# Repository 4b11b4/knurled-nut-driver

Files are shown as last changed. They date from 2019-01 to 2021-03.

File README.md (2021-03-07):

# Knurled Nut Driver
## Description
3D printed drill bit designed for tightening knurled nuts on 3.5mm jacks.<br>
Knurled nuts are common in [Eurorack](http://www.doepfer.de/a100_man/a100m_e.htm) systems.

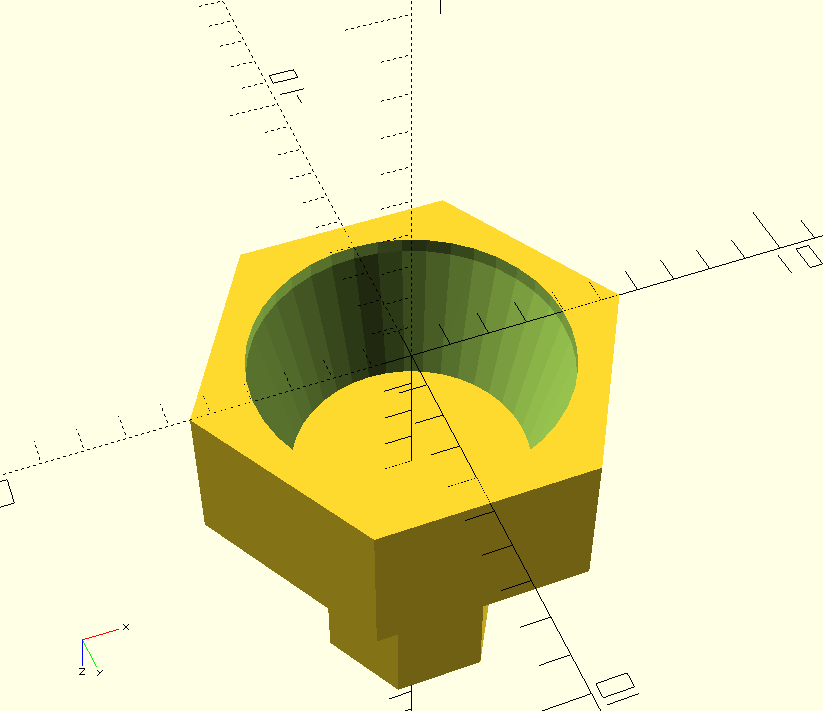
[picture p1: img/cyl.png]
Knurled Nut Suction Cup


## Instructions for Printing and Use
See a [writeup](https://4b11b4.com/k2nd.html) here.

## Features
* __alignment__: no need to align the two metal extensions
* __plastic__: if you have an accident, you will not scratch the module
* __inexpensive__: very little material, easily replaceable
* __parametric__: can be modified to multiple drill bit sizes
* __durable__: no small tips which can break off or become damaged
* __simple__: very easy to print, simple design which uses friction forces
* __useable with power tools__: most people will warn you
  (generally) to never use
  power tools for tightening these nuts, as over tightening may damage the
  jack.

## Why?
This design will not damage your jack
if used with a power tool.
When the nut is tightened, the design of the
bit will simply cause it to slip rather than over-torque the nut.
(note: of course, you can <b>still</b> overtorque by pressing down too hard
<br><br>
In this scenario, you may cause extra wear
to the bit, but the jack will not be damaged.<br><br>

Even more preferable is to use a small precision electric drill with an
adjustable clutch to set the desired torque. You can see (and hear) this
in action [here](https://www.youtube.com/watch?v=a87VO5FZRd8).

## Recommended Power Tool
[See the writeup](https://4b11b4.com/k2nd.html) for links to the two power tools I used.
Those affiliate links don't work...

## Alternative Tools:
[Exploding Shed](https://www.exploding-shed.com/shop-catalogue/various/)

[Xicon Driver](https://www2.mouser.com/ProductDetail/Xicon/382-0006/?qs=sGAEpiMZZMv9NFGNGF1lwkQZlGfFTqj%252b)

[Adachi-san Driver](http://www.tabiwallah.com/radiowallah/shops/jacknut.html)

[Philmore](https://www.fullcompass.com/prod/026125-philmore-nt500-knurled-nut-tool-)

[Homemade](https://www.muffwiggler.com/forum/viewtopic.php?t=114781&start=all&postdays=0&postorder=asc)

[Also homemade](https://www.muffwiggler.com/forum/viewtopic.php?t=5408)

[Homemade 3](http://www.n1gy.com/homebrewed-audio-jack-tool.html)

[Wiha](https://www.wihatools.com/precision-nut-driver-3-5-x-60mm)

[Wiha Bit](https://www.wihatools.com/sys-4-nut-driver-blade-3-5mm)

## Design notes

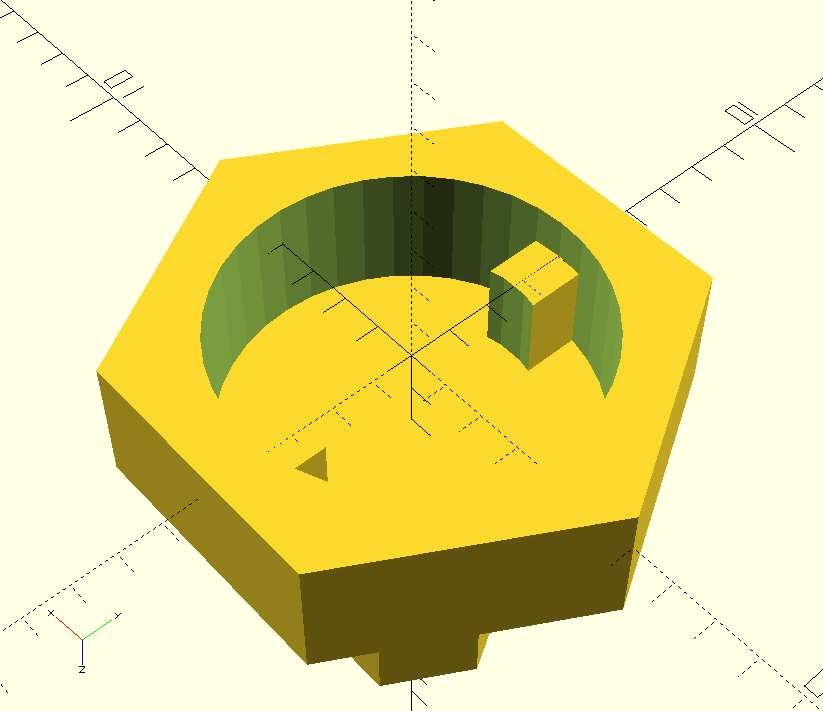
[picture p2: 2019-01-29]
img/nub.png

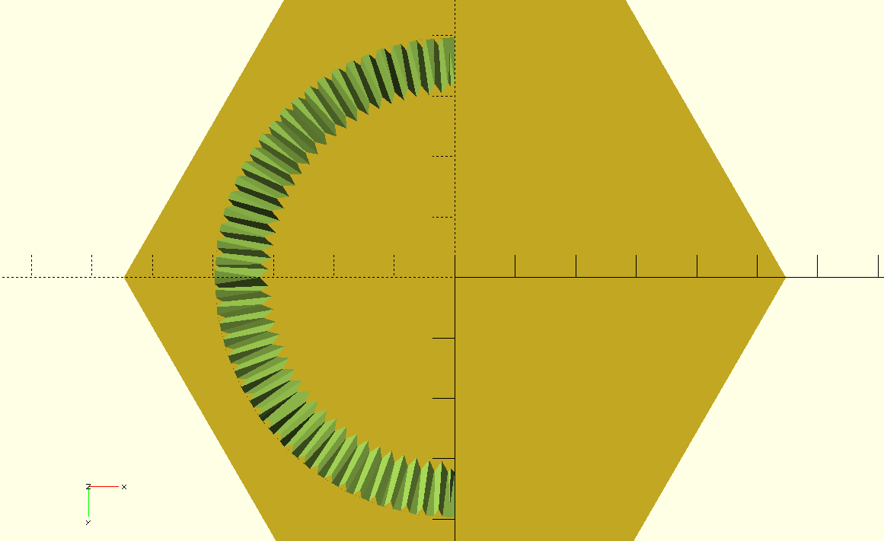
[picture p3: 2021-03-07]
img/cyl_cutout_30deg_teeth_bottom.png

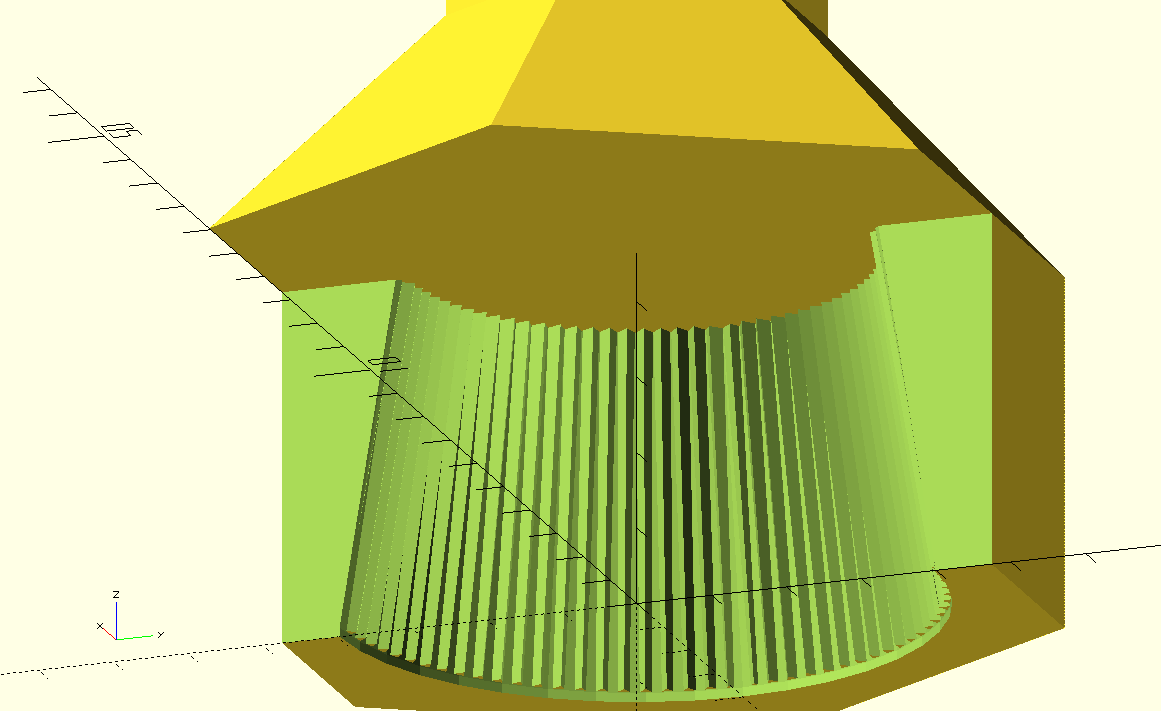
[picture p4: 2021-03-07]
img/cyl_cutout_30deg_teeth.png

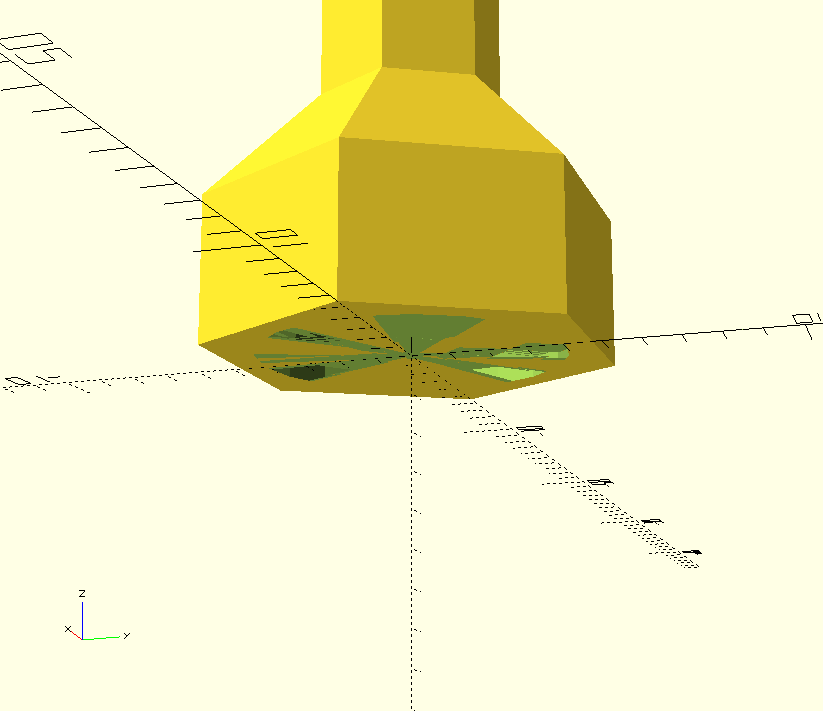
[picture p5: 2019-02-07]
img/cyl_cutout_20deg.png

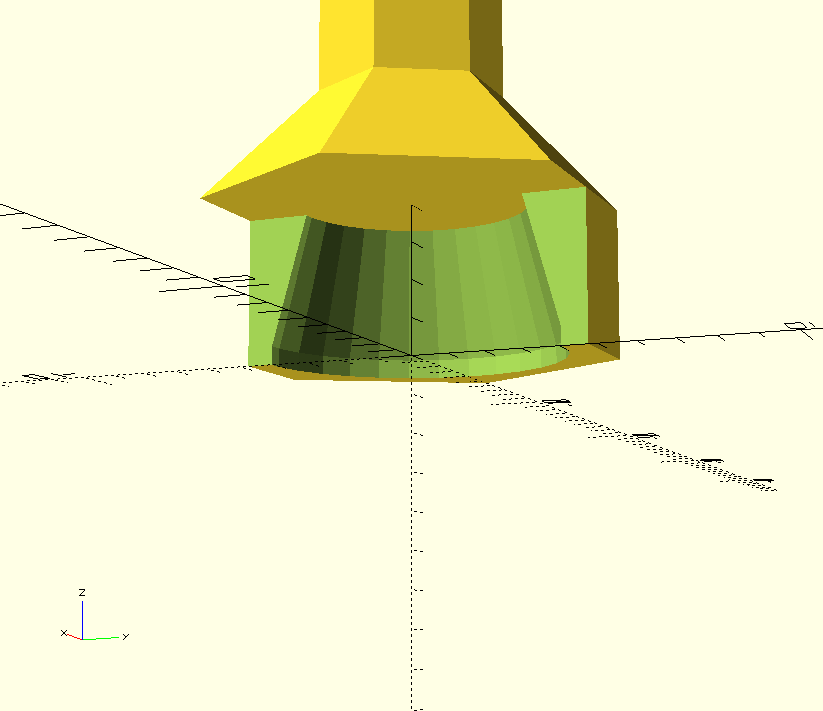
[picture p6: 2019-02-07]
img/cyl_cutout_30deg.png

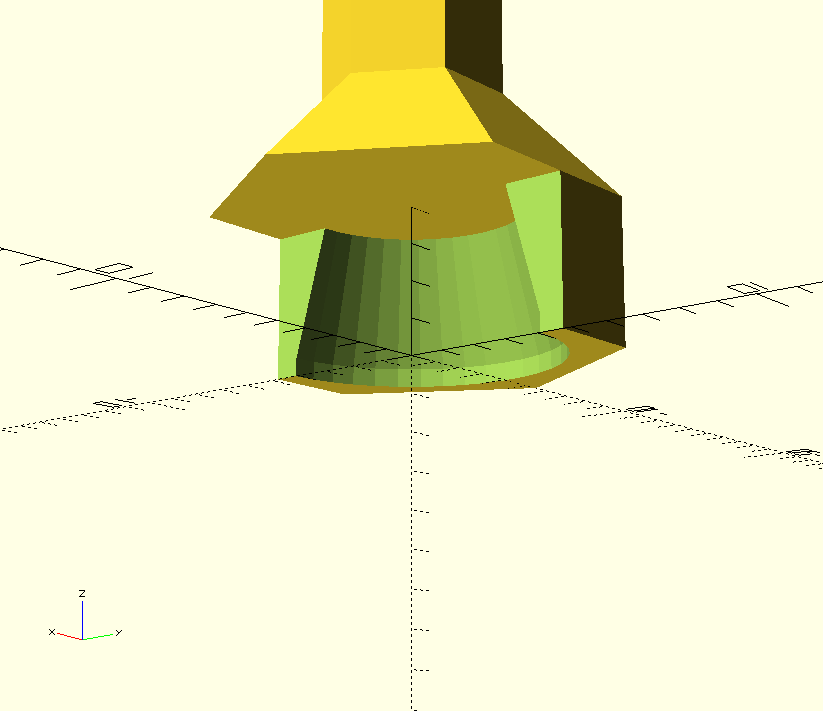
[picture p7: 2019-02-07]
img/cyl_cutout.png

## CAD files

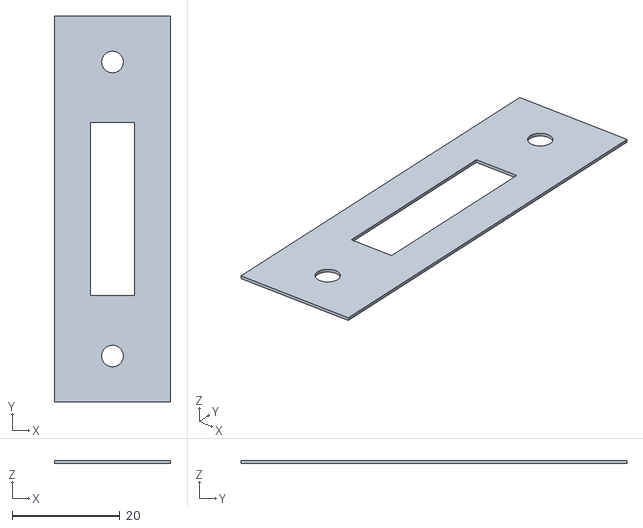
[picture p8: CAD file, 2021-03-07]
scad/doorbell_enclosure.stl
21.5 x 71.5 x 0.5

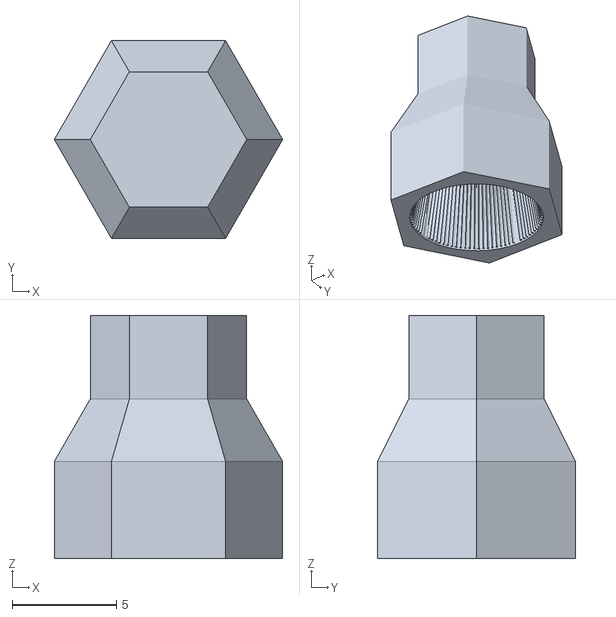
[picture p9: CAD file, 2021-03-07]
stl/ktorq-h7.1.stl
10.9 x 9.48 x 11.7

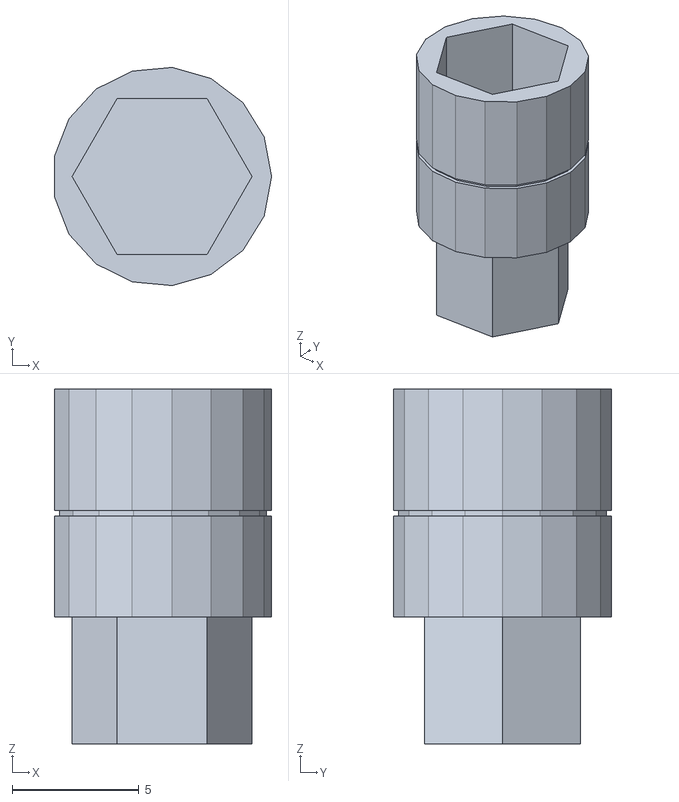
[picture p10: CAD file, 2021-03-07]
stl/hextension.stl
8.57 x 8.60 x 14.0

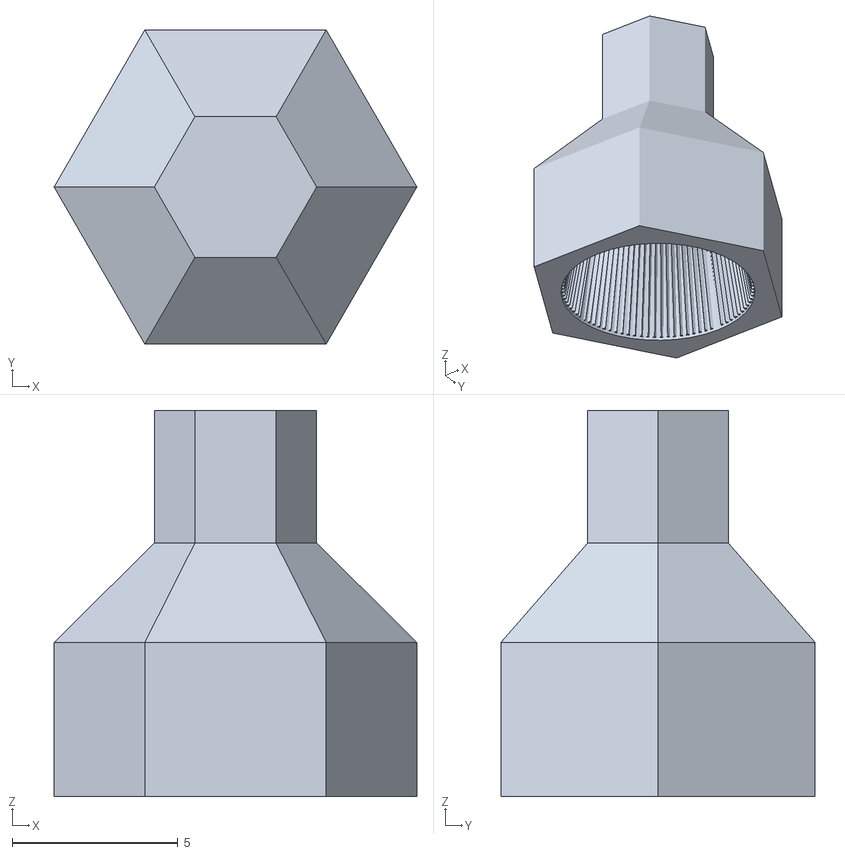
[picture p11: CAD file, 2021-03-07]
stl/ktorq-h4.5.stl
10.9 x 9.48 x 11.7

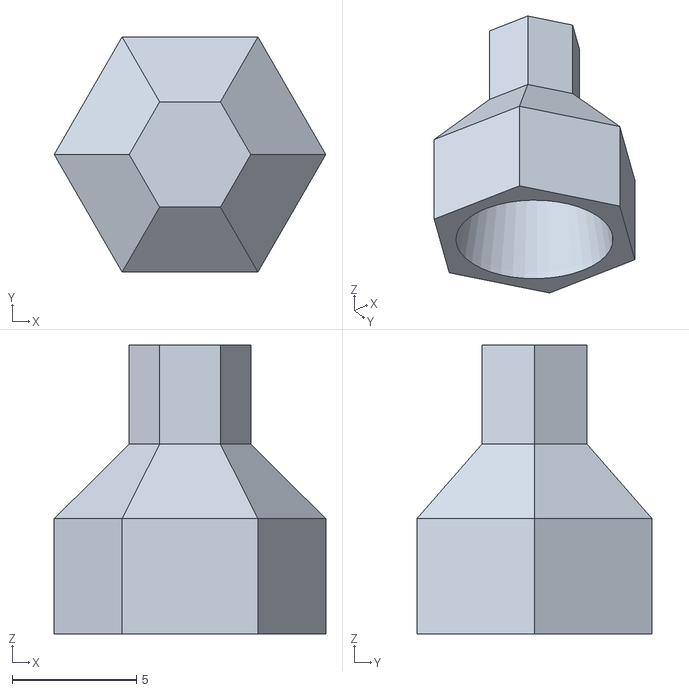
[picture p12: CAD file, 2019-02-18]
stl/knsc-r_dec_.75-r_twe_.125.stl
10.9 x 9.48 x 11.7

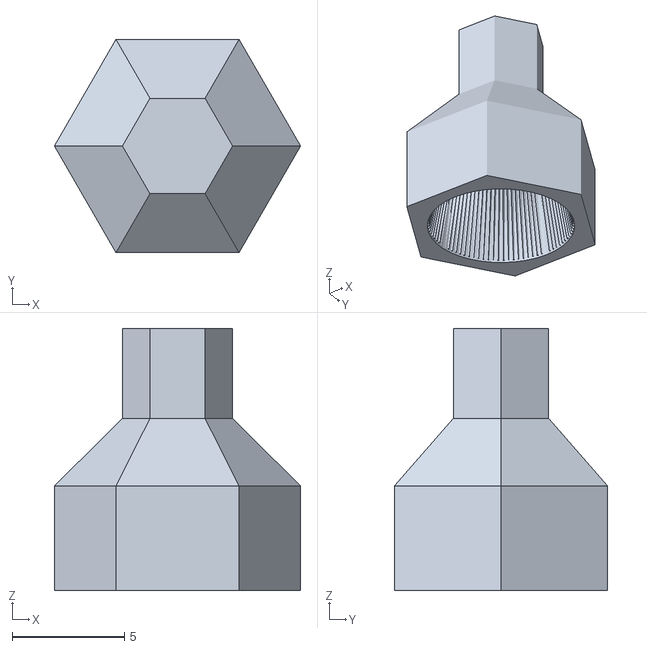
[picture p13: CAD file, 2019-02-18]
stl/knsc-r_dec_.75-r_twe_.125-r_step_0.15.stl
10.9 x 9.48 x 11.7

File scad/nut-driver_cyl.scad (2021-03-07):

// Anton Bilbaeno
// 4b11b4
// github: 4b11b4
// thingiverse: 4b11b4
// www.4b11b4.com
// 1/30/2019



// A model for a 3D printed drill bit designed to tighten 3.5mm
// knurled nuts. These are common in Eurorack synthesizer modules.

// This drill bit is unique in that most designs feature "nubs" to
// fit into two "slots" on these knurled nuts. This design completely
// ignores those "slots". Instead, the inside of the "grip" is a cone
// shape. In other words, the cutout is a cylinder with a decreasing
// diameter as it goes up.

// Instead of having "nubs" which fit into the "slots" of the knurled
// nut, this "grip" simply uses friction. A small amount of downward
// force is required. This does cause the "grip" to wear out over time.
// However, as you wear out one layer (i.e. each "layer" created by the
// 3D printer), the layer above it will begin to grip the knurled nut.

// With the proper driver, the bit can be used to tighten knurled
// nuts to an appropriate level of torque.

// It may be possible to design some even more complex structures
// inside the bit, so that as you wear out one layer, you will reach
// a completely new grip. This would eventually require removing
// some of the face of the bit (i.e. sanding down the front).



// While tweaking the variables below, it is helpful to see the inside of
// the bit. You will find a helpful comment in the grip() definition below.



// REAL-WORLD MEASUREMENTS USING METAL CALIPERS (mm)
// If default .STL files do not work, try check these measurements.
KNURL_D_MEASURE = 7.70; //measured outer diameter of a knurled nut
KNURL_H_MEASURE = 1.87; //height of a knurled nut
THREAD_H_MEASURE = 4.65; //height of threads on jack
//common drill bit sizes: 7.1, 4.5mm
BIT_D_MEASURE = 7.1;

// PRINTER TWEAKS (you may experiment)
// depends on filament size, layer heights, print temperature, etc
// you may find slightly better results by tweaking these

KNURL_R_TWEAK = 0.125 ; //increase if nut does not fit
KNURL_H_TWEAK = 1.75; //reduce height of lip at end of bit, max=KNURL_H_MEASURE
BIT_R_TWEAK   = 0.200; //increase if shaft does not fit snugly
GRIP_H_TWEAK = 0.00; //increase if bit bottoms out. knurl_h is 1.87mm, so THREAD_H_MEASURE should be an extra 1.87mm too big already...? assuming the "grip" area is hitting the jack at the top

// VARIABLES SETUP (you may change)
GRIP_SHELL = 1.50; //thickness outside wall <-> grip cutout
GRIP_R_CHANGE = 0.750; //how much the grip radius decreases
SHAFT_HEIGHT            = 4;   //shaft is inserted into drill chuck
TRANSFER_HEIGHT         = 3;   //"transfer" is between the bit and shaft
OUTER_NUM_ANGLES        = 6;   //usually bits are a hexagon...
GRIP_NUM_ANGLES         = 40;  //the number of "teeth"
KNURL_R_STEP = -0.1;
KNURL_H_STEP = 0.0125;

// FINAL VARIABLE SETUP (do not change)
KNURL_R        = KNURL_D_MEASURE/2 + KNURL_R_TWEAK;
KNURL_H        = KNURL_H_MEASURE - KNURL_H_TWEAK;
GRIP_INNER_RADIUS   = KNURL_R - GRIP_R_CHANGE;
GRIP_HEIGHT         = THREAD_H_MEASURE + GRIP_H_TWEAK;   //size of inside cone
BIT_RADIUS          = BIT_D_MEASURE/2 + BIT_R_TWEAK;
OUTER_RADIUS        = KNURL_R + GRIP_SHELL;



union() {
  difference() {
    grip();
    /////// UNCONMMENT TO VIEW CROSS-SECTION OF BIT
    //translate([0,-500,-100]) cube(1000,1000,1000);
    ///////
  }
  transfer();
  shaft();
};

module grip() {
  union() {
    
    difference() {
      cylinder(r=OUTER_RADIUS,h=GRIP_HEIGHT,$fn=OUTER_NUM_ANGLES); //outside cylinder solid
      cylinder(r=KNURL_R,h=KNURL_H,$fn=GRIP_NUM_ANGLES); //KNURL_H ("lip") cylinder cutout
      translate([0,0,KNURL_H]) //cone cutout "cylinder with decreasing radius"
        cylinder(r1=KNURL_R,r2=GRIP_INNER_RADIUS,h=GRIP_HEIGHT-KNURL_H,$fn=GRIP_NUM_ANGLES);
    }
    
    kk1();
  }
}

module kk1() {
  difference() {
    translate([0,0,KNURL_H+KNURL_H_STEP]) //cone cutout "cylinder with decreasing radius"
      cylinder(r=KNURL_R, h=GRIP_HEIGHT-KNURL_H, $fn=GRIP_NUM_ANGLES*2);
    translate([0,0,KNURL_H+KNURL_H_STEP]) //cone cutout "cylinder with decreasing radius"
      cylinder(r1=KNURL_R-KNURL_R_STEP,r2=GRIP_INNER_RADIUS, h=GRIP_HEIGHT-KNURL_H, $fn=GRIP_NUM_ANGLES/10);
    
    KK_MULT = 90;
    for (i=[0:KK_MULT]) {
      translate([0,0,KNURL_H+KNURL_H_STEP]) { //cone cutout "cylinder with decreasing radius"
        rotate([0,0,i*(360/KK_MULT)])
          cylinder(r1=KNURL_R-KNURL_R_STEP,r2=GRIP_INNER_RADIUS, h=GRIP_HEIGHT-KNURL_H, $fn=GRIP_NUM_ANGLES/KK_MULT);
      }
    }
  }
}

module transfer() {
  translate([0,0,GRIP_HEIGHT])
    cylinder(r1=OUTER_RADIUS,r2=BIT_RADIUS,h=TRANSFER_HEIGHT,$fn=OUTER_NUM_ANGLES);
}

module shaft() {
  translate([0,0,GRIP_HEIGHT+TRANSFER_HEIGHT])
    cylinder(r=BIT_RADIUS,h=SHAFT_HEIGHT,$fn=OUTER_NUM_ANGLES);
}

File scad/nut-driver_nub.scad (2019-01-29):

d=7.75; //measured
doffset=0.3;
outer=12;

flathead=1.25;
foffset=0.0;
fheight=3;
fbase=0;

nheight=0.95;
nwidth=1.25;
htransfer=4;
dgrip=4.5;
dgrip_offset=0.3;
hgrip=3;

union() { 
    
    // cylinder cutout of outer hexagon  
    difference() {
      translate([0,0,-nheight]) cylinder(r=outer/2,h=fheight+fbase,$fn=6);
      translate([0,0,-nheight]) cylinder(r=((d+doffset)/2),h=fheight+nheight,$fn=40);
      //cube(50,50,50);
    }
    
    //nubs
    difference() {
      rectangle();
      cylinder(r=((d+doffset)/2)-nwidth,h=fheight,$fn=30);
    }
    
    
    // transfer + grip
    translate([0,0,-nheight+fheight+fbase]) cylinder(r1=outer/2,r2=dgrip/2,h=htransfer,$fn=6);
    translate([0,0,-nheight+fheight+fbase+htransfer]) cylinder(r=dgrip/2,h=hgrip,$fn=6);
};

module rectangle() {
    w=flathead-foffset;
    l=outer-2;
    h=fheight-nheight;
    translate([0,0,h/2]) cube([w,l,h], center=true);
}

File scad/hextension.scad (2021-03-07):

SIDES = 6;


//BIT
BIT_DIAMETER = 7.1;
BIT_LENGTH = 7;

cylinder(
r=BIT_DIAMETER/2,
h=BIT_LENGTH,
$fn=SIDES);


//EXTENSION
EXT_THICKNESS = 0.77;
EXT_OVERLAP = 2;
EXT_LENGTH = 7 + EXT_OVERLAP;
EXT_SIDES = 17;
NOTCH_HEIGHT = 0.2;
NOTCH_DEPTH = 0.2; 

translate([0,0,BIT_LENGTH-EXT_OVERLAP])
difference() {
  //extension
  difference() {
    cylinder(
    r=BIT_DIAMETER/2+EXT_THICKNESS,
    h=EXT_LENGTH,
    $fn=EXT_SIDES);

    cylinder(
    r=BIT_DIAMETER/2,
    h=EXT_LENGTH,
    $fn=6);
  }
  
  //notch
  translate([0,0,EXT_OVERLAP*2])
  difference() {
    cylinder(
      r=BIT_DIAMETER/2+EXT_THICKNESS,
      h=NOTCH_HEIGHT,
      $fn=EXT_SIDES);
    cylinder(
      r=BIT_DIAMETER/2+EXT_THICKNESS-NOTCH_DEPTH,
      h=NOTCH_HEIGHT,
      $fn=EXT_SIDES);
  }
}

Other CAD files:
stl/knsc-r_dec_.75-r_twe_.125-r_step_0.1.stl
stl/knsc-r_dec_.75-r_twe_.15.stl

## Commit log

2019-01-30 can also insert an html line break (for github flavored markdown?)
2019-02-06 comments and variable names
    [nut-driver_cyl.scad]
2019-02-06 variable names
    [nut-driver_cyl.scad]
2019-02-06 collapsing variables
    [nut-driver_cyl.scad]
2019-02-07 variable collapse
    [nut-driver_cyl.scad]
2019-02-07 measured height more accurate
    [nut-driver_cyl.scad]
2019-02-16 re-arrange variables, re-measure, re-gen stl with different parameters. first trial seems that the radius decrease of inner cone is too small
    [nut-driver.scad, nut-driver.stl, nut-driver_cyl.scad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]
2019-02-16 re-org, re-export stl w/o cutout
    [knsc-r_dec_.75-r_twe_.15.stl, nut-driver_cyl-r_dec-0.75.stl, nut-driver_cyl.scad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]
2019-02-18 create teeth
    [knsc-r_dec_.75-r_twe_.125-r_step_0.1.stl, knsc-r_dec_.75-r_twe_.125-r_step_0.15.stl, knsc-r_dec_.75-r_twe_.125.stl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]
